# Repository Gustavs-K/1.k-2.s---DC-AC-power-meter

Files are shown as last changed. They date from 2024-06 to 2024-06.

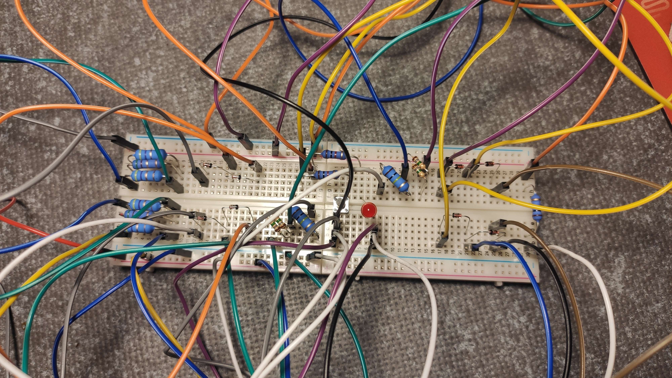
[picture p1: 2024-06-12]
Praktiskie_atteli/Elek_prototype_image2.jpg

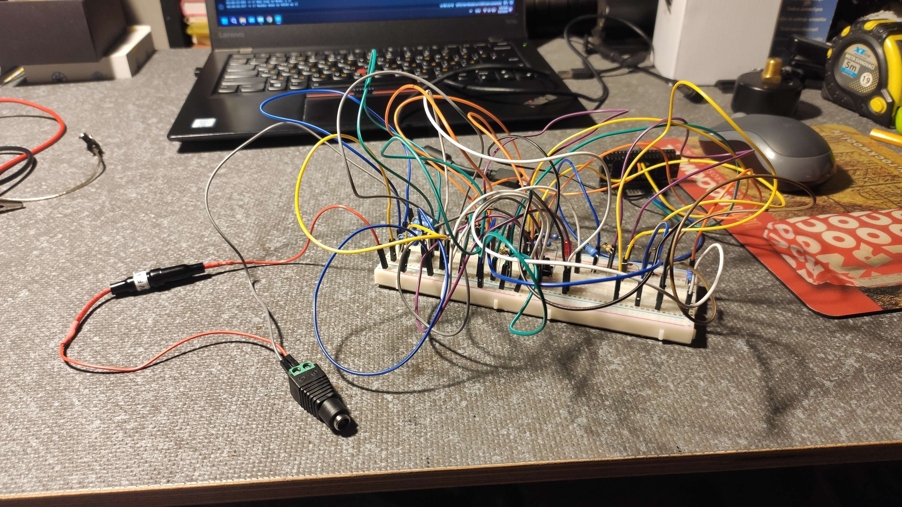
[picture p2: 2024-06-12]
Praktiskie_atteli/Elek_prototype_image1.jpg

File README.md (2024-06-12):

# 1.k 2.s DC/AC power meter

Elek_merijumu-jaudas_metrs / Elek_merijumu-jaudas_metrs.ino --- Kods

Praktiskie_atteli / ... --- Praktiskā prototipa attēli

DC AC power meter - atskaite.docx --- Atskaite

Elek-mer-projekts.fzz --- Fritzint makets

Parallel-resistor-calc.xlsx --- Paralelo rezistoru kalkulators

Power-meter-fritzing_mockup.png --- Fritzing maketa bilde

Power-meter_LTspice_model.png --- LTspice modeļa bilde

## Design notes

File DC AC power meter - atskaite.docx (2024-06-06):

DC / AC jaudas mērītājs // Atskaite

Kods, atskaite un vairāki pielikumi ir arī pieejami GitHub:
https://github.com/Gustavs-K/1.k-2.s-DC-AC-power-meter/

Kods satur komentārus, kas paskaidros koda darbību daudz dziļākā līmenī.
Visi komentāri ir angļu valodā.

# Īss aprakts

Projekta galvenais mērķis ir izveidot jaudas mērītāju, kas spēj nomērīt un aprēķināt līdzstrāvas un maiņstrāvas spriegumus, strāvas stiprumus un jaudas.

Projekts iekļauj ESP32, kas pilda ADC un informācijas apstrādes funkcijas un vairākas elektroniskās ierīces, kas pārveido ienākošo spriegumu un slodzes patērēto stāvas stiprumu uz MCU nolasāmu formu un veic citas funkcijas.

# Galvenās funkcijas

Mikrokontrolleris – ESP32_Devtikc_V4 – ADC , datu apstrāde, datu izvade caur “serial monitor”,

2x Sprieguma dalītājs – samazina nolasāmo spriegumu, lai iekļautos ESP32 3.3V nolasāmajā diapazonā,

2x Pilna viļņa taisngriezis – pārveido negatīvo maiņstrāvas spriegumu uz pozitīvu un ar ESP32 nolasāmu,

Šunta rezistors – Strāvas stipruma mērīšanai

LED (sarkans) – pārsprieguma indikators,

Poga – DC / AC režīma pārslēgšanai.

# Saturs

# Elektronika

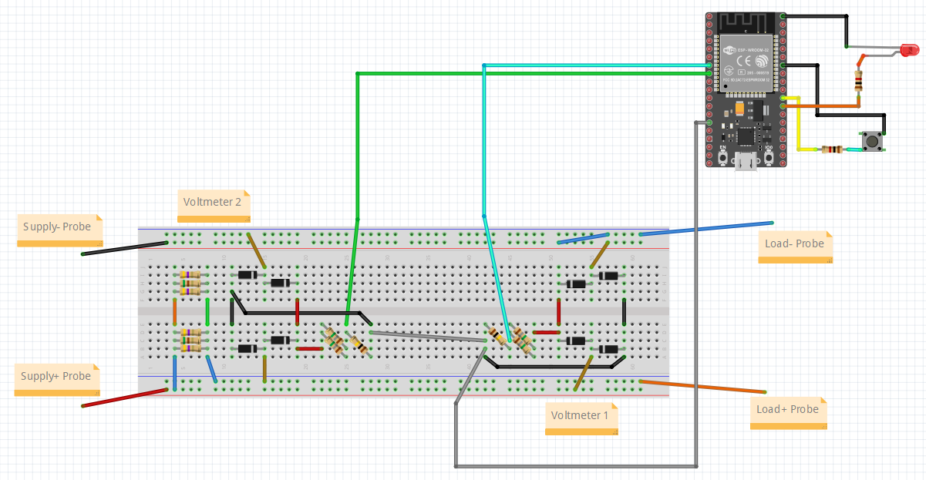
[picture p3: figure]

## Voltmetri

Voltmetri sastāv no pilna viļņa taisngrieža, sprieguma dalītāja un ESP32 analogās ieejas. V1 mēra kopējo ķēdes spriegumu un V2 mēra spriegumu pēc šuntes, lai varētu aprēķināt tās sprieguma kritumu.

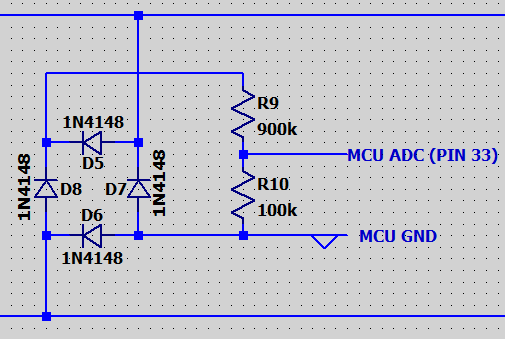
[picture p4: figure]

Oriģināli bija iedomāta sistēma ar vairākiem režīmiem, kurā katrs režīms pielietotu savu detaļu kombināciju. Šī ideja tika atmesta, lai vienkāršotu jaudas metra pielietošanu un izveidi, bet tādējādi arī zaudējot mazliet precizitāti un ieviešot apgrūtinājumus datu apstrādē.

## Sprieguma dalītājs

Spieguma dalītājs sastāv no diviem 1.8M Ω rezistoriem (kopā 900k Ω) un viena 100k Ω rezistora. Šīs vērtības kopā izveido izejas pret ieejas sprieguma attiecību 1/10, kas palielina ESP32 nolasāmo diapazonu no 3.3V uz 33V.

Lielās rezistoru vērtības tika izvēlētais, lai samazinātu voltmetru ietekmi uz mērāmās ķēdes darbību.

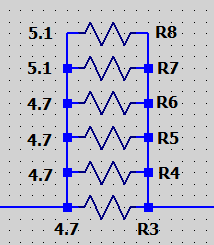
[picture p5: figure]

## Šuntes rezistors

Šuntes rezistors sastāv no sešiem, paralēli novietotiem, rezistoriem, kuru vērtības ir 4x 4.7 Ω un 2x 5.1 Ω. Oriģināli 0.805 Ω šunte bija iedomāta, bet, pieejamo rezistoru vērtību dēļ, 0.8044 Ω bija tuvākā iegūstamā kopējā pretestība, kas spētu izdalīt pietiekami daudz jaudas un izmantotu pēc iespējas mazāku rezistoru daudzumu. 0.805 Ω tika izvēlēts, lai pie maksimālā nomērāmā spieguma krituma (3.3V) strāvas stiprums būtu apmēram 4 ampēri.
Meklējot rezistoru kombināciju, maksimālais plānotais strāvas stiprums tika samazināts līdz 3 ampēriem.

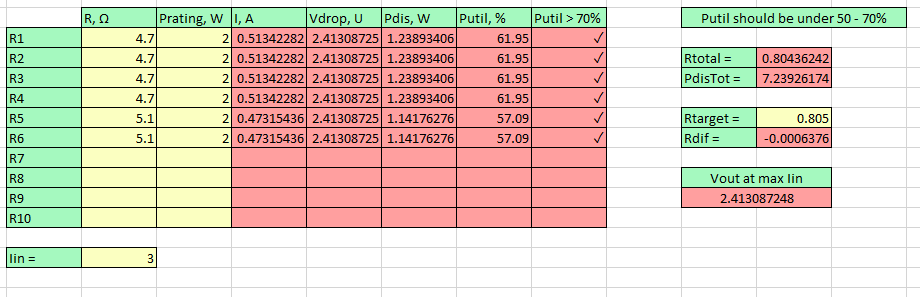
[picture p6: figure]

Izveidojot voltmetra maketu, maksimālais strāvas stiprums samazinājās līdz 1 ampēram, maketēšanas plates un vadu savienojumu dēļ.

## Pilna viļņa taisngriezis

Pilna viļņa taisngriezis ir izveidots no 1N4148 diodēm. Šī detaļa tiek izmantota, lai pārveidota maiņstrāvas negatīvās vērtības uz pozitīvām, kuras ESP32 var nolasīt.

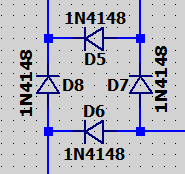
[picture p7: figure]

Mērot līdzstrāvu šis taisngriezis darbojas kā pret polaritātes aizsardzība.

Šis taisngriezis nesatur filtra kondensatoru, jo tas apgrūtinātu datu apstrādi un mērījumu veikšanai tas nav nepieciešams.

Viens no taisngrieža lielākajiem mīnusiem ir diožu sprieguma kritums, kas iespaido gan līdzstrāvas, gan maiņstrāvas mērījumu precizitāti.

## Poga un LED

Pogas galvenā funkcija ir DC / AC režīma pārslēgšana. Šis režīms maina apstrādes laikā veiktās funkcijas un izvadītos datu.

LED indikators norāda uz pārspriedumu uz ESP32 analogajām ieejām. Šī funkcija tiek veikta ar koda palīdzību. Ekstrēmos gadījumos indikators varētu nestrādāt kā iecerēts.

## ESP32

ESP32 ADC ir ļoti ierobežots. Kaut arī tas ir 12 bitu ADC, tā mērījumi var būt ievērojami atšķirties, sevišķi pie maksimālajām un minimālajām vērtībām, kur mērījumi sāk ievērojami diverģēt no īstā sprieguma.

ESP32 datu apstrādes spējas ir ļoti labas, divu kodolu un 80 – 240 MHz takts frekvences dēļ. Vidējais koda cikla laiks ir ≈80 ms, no kura ≈60 ms ir analogo datu nolasīšana un ≈10µs datu apstrāde.

## Cenas aprēķins:

ESP32-DEVKITC-S1 – 17.13 EUR

1N4148 diode – 0.04 EUR x8

Rezistori :

4.7 Ω, 2W – 0.09 EUR x4

5.1 Ω, 2W – 0.20 EUR x2

1k Ω – 0.09 EUR x2

100k Ω – 0.09 EUR x2

1.8M Ω – 0.01 EUR x4

LED (sarkans) – 0.06 EUR

Maketēšanas plate – 4.83 EUR x2

Kopējā cena – ≈28.33 EUR

# Koda apraksts

Galvenais cikls sastāv ko 4 galvenajām funkcijām, starp kurām tiek nomērīti šo funkciju darbības laiki.

## varResetter() funkcija

Šī funkcija pārmaina visu aprēķināto mainīgo vērtības uz 0, lai nodrošinātu, ka iepriekšējie cikli neietekmē šī cikla aprēķinus.

## inputReader() funkcija

inputReader() galvenokārt nolasa un saglabā V1 un V2 analogās vērtības, pārbauda un veic pogas funkcijas un pārbauda un ieslēdz pārsprieguma LED.

## dataProcessor() funkcija

Šī funkcijas apstrādā nolasītos datus, lai iegūt vērtības, kuras nav iespējams tieši nolasīt. Dati, kurus šī funkcija aprēķina, ir atkarīgi no režīma. DC režīmā tiek aprēķināts vidējais strāvas stiprums un jauda. AC režīmā tiek aprēķinātas RMS vērtības priekš V1, V2, I, īstā jauda, šķietamā jauda, reaktīvā jauda un jaudas faktors.

## outputPrinter() funkcija

outputPrinter() izvada visas izvadāmo mainīgo vērtības serial monitora. Līdzīgi dataProcessor(), šī funkcijas izvadītā informācija ir atkarīga no darbības režīma.

RTU // EVIF // RECO 0 // Gustavs Krūzmanis // 231REC066

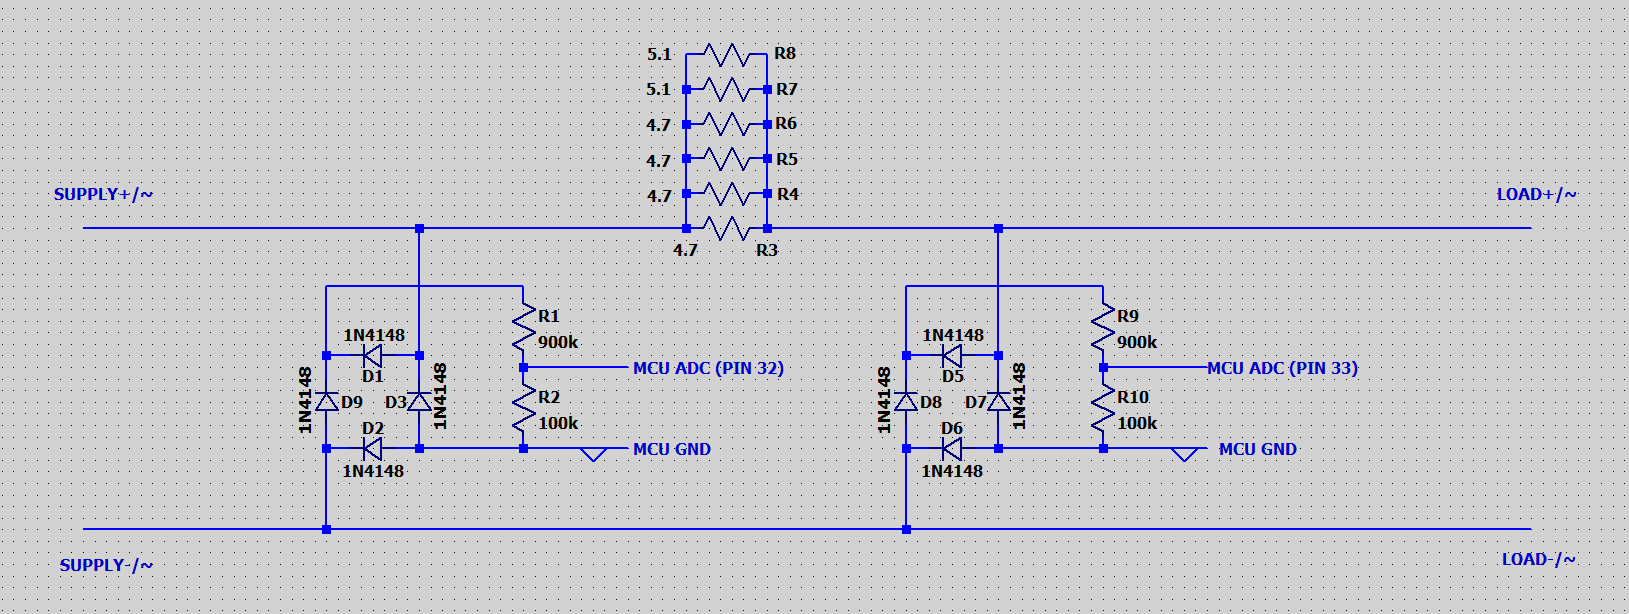
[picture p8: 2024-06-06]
Power-meter_LTspice_model.png

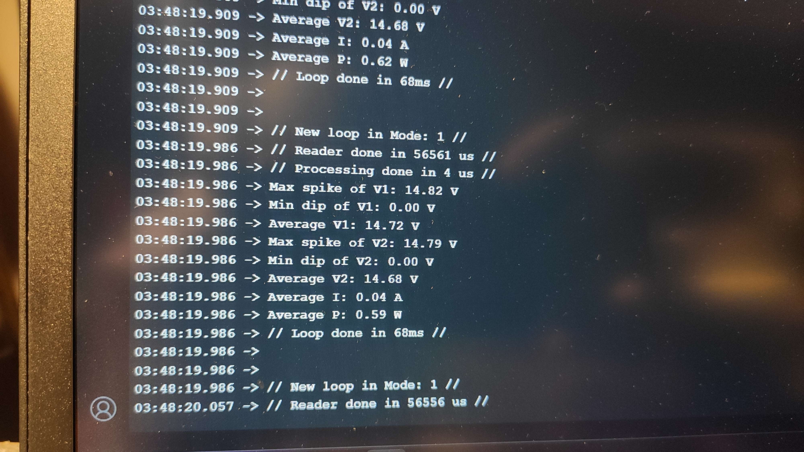
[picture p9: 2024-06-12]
Praktiskie_atteli/Elek_prototype_image-merijumi1.jpg

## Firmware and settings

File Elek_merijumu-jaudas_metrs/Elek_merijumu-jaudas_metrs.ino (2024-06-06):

#include <Arduino.h>

// Main info
// 2 Modes: 1) DC Power ; 2) AC Power

// Mode info:
// 1) DC P --- Terminals(4): Supply in/out , Load in/out ; ONLY IN SERIES ; SPLY- & LOAD- connected , Voltage(SPLY+/SPLY- --> VD1 --> MCU) , Amperage(SPLY+/LOAD+ --> SHNT --> VD2 --> MCU)
// 2) AC P --- Terminals(4): Supply in/out , Load in/out ; ONLY IN SERIES ; SPLY- & LOAD- connected , Voltage(SPLY+/SPLY- --> FWB1 --> VD1 --> MCU) , Amperage(SHNT --> FWB2 --> VD2 -->  MCU)

// Devices:
// ESP32 (MCU)               ---  PINS: 
// Indicator LED red (LEDR)  ---  For over voltage warning
// Voltage devider (VD1)     ---  For V1
// Voltage devider (VD2)     ---  For V2 (I)
// Shunt resistor (SHNT)     ---  For I
// Full wave bridge 1 (FWB1) ---  For AC V1
// Full wave bridge 2 (FWB2) ---  For AC V2 (I)

// Measured power supply (SPLY)
// Measured load (LOAD)

// Button debuging, leave undefined for no extra info
#define BUTTON_DEBUGING_SERIAL_INFO 

// Leave undifined for no extra timers
#define MORE_TIME_MEASUREMENTS 1

// Analog input buffer size
#define BUFFER_SIZE 200

// Shunt resistors resistance
#define SHUNT_RESISTANCE 0.80436242

// Defins the output to input ratio of voltage dividors (1 / x)
#define VD1_RATIO 10
#define VD2_RATIO 10

// Defines least significant bits
#define LSB_V1 3.3F/4095.0f
#define LSB_V2 3.3F/4095.0f
#define LSB_I LSB_V2
#define LSB_P LSB_V1*LSB_I

// Pins
#define PIN_V1 33
#define PIN_V2 32
#define PIN_LED 16
#define PIN_BUTTON 17

// Stores if button is pressed down
int buttonState;
// Denots the current selected mode
uint16_t selectedMode = 1;

// Buffers for analog measurements (voltage and amperage)
uint16_t bufferV1[BUFFER_SIZE];
uint16_t bufferV2[BUFFER_SIZE];

// Processing variables
uint64_t sumV1 = 0;
uint64_t sumV2 = 0;

// Unique to AC
int64_t rmsSumV1 = 0;
int64_t rmsSumV2 = 0;
int64_t rmsSumI = 0;
int64_t realPowerSum = 0;

// Output variables
float spikeMaxV1 = 0;
float spikeMaxV2 = 0;

float dipMinV1 = 4095;
float dipMinV2 = 4095;

float avgV1 = 0;
float avgV2 = 0;

float avgI = 0;

// Unique to DC
float avgP = 0;

// Unique to AC
float rmsV1 = 0;
float rmsV2 = 0;
float rmsI = 0;
float realPower = 0;
float apparentPower = 0;
float reactivePower = 0;
float powerFactor = 0;

// Only executed on power on
void setup() {
  // Starts serial monitor, with baud rate of 115200
  Serial.begin(115200);
  Serial.println("// Start up begin //");

  // Initiates the pins
  pinMode(PIN_V1, INPUT);
  pinMode(PIN_V2, INPUT);
  pinMode(PIN_LED, OUTPUT);
  pinMode(PIN_BUTTON, INPUT_PULLUP);

  // Turns the LED off
  digitalWrite(PIN_LED, LOW);
  
  // Measures the length of the setup function in milliseconds
  unsigned long millisOut = millis();
  Serial.print("// Start up done in ");
  Serial.print(millisOut);
  Serial.println("ms //");
}

void loop() {
  
  Serial.print("\n// New loop in Mode: ");
  Serial.print(selectedMode);
  Serial.println(" //");
  unsigned long loopMillis = millis();

  // Only adds extra timer variables, if extra timers ar on
  #ifdef MORE_TIME_MEASUREMENTS
    unsigned long readerMicros;
    unsigned long processingMicros;
  #endif
  
  // Resets variables, so last cycle dosn't effect this cycle
  varResetter();  

  // Extra timer for reader starts
  #ifdef MORE_TIME_MEASUREMENTS
    readerMicros = micros();
  #endif

  // Reads and writes analog inputs, handels button and LED functions 
  inputReader();

  // Extra timer for inputReader ends and dataProcessor starts
  #ifdef MORE_TIME_MEASUREMENTS
    readerMicros = micros() - readerMicros;
    Serial.print("// Reader done in ");
    Serial.print(readerMicros);
    Serial.println(" us //");

    processingMicros = micros();
  #endif

  // Processes analog data
  dataProcessor();

  // Extra timer for dataProcessor ends
  #ifdef MORE_TIME_MEASUREMENTS
    processingMicros = micros() - processingMicros;
    Serial.print("// Processing done in ");
    Serial.print(processingMicros);
    Serial.println(" us //");
  #endif

  // Prints outputs to serial monitor
  outputPrinter();

  Serial.print("// Loop done in ");
  loopMillis = millis() - loopMillis;
  Serial.print(loopMillis);
  Serial.println("ms //\n");
}

// Resets variables, so last cycle dosn't effect this cycle
void varResetter(){
  
  // Processing variables
  sumV1 = 0;
  sumV2 = 0;

  // Unique to AC
  rmsSumV1 = 0;
  rmsSumV2 = 0;
  rmsSumI = 0;
  realPowerSum = 0;

  // Output variables
  spikeMaxV1 = 0;
  spikeMaxV2 = 0;

  dipMinV1 = 4095;
  dipMinV2 = 4095;

  avgV1 = 0;
  avgV2 = 0;

  avgI = 0;

  // Unique to DC
  avgP = 0;

  // Unique to AC
  rmsV1 = 0;
  rmsV2 = 0;
  rmsI = 0;
  realPower = 0;
  apparentPower = 0;
  reactivePower = 0;
  powerFactor = 0;

}

// Reads and writes analog inputs, handels button and LED functions
void inputReader(){
  // 4 = button was pressed down / 2 = button was up
  int buttonLatch;
  bool ledStillOn;

  // Cycle every buffer entry
  for(int i = 0; i < BUFFER_SIZE; i++){
    // Reads button state 
    buttonState = digitalRead(PIN_BUTTON);
    ledStillOn = false;

    // Button checker
    // Only execute every 10th cycle
    if (i % 10 == 0){
      // Switch statement uses a hash, that is comprised of the current button state and the previous for cycles button state
      switch (buttonState + buttonLatch){
        default:
          buttonLatch = 2;
          Serial.println("/// BUTTON HASH MISMATCH ERROR ///");
        break;

        case 3:
          // Not pressed / wasn't pressed
          #ifdef BUTTON_DEBUGING_SERIAL_INFO
            // Serial.println("No button activity");
          #endif
        break;

        case 2:
          // Is pressed / wasn't pressed
          Serial.println("BUTTON CLICK!!!");

          buttonLatch = 4;

          ++selectedMode;
          if(selectedMode >= 3){
            selectedMode = 1;
          }

        break;

        case 5:
          // Isn't pressed / was pressed
          buttonLatch = 2;
          #ifdef BUTTON_DEBUGING_SERIAL_INFO
            // Serial.println("BUTTON RESET");
          #endif
        break;

        case 4:
          // Is pressed / was pressed
          #ifdef BUTTON_DEBUGING_SERIAL_INFO
            // Serial.println("Button is held down");
          #endif
        break;
      }

    }

    // Read and store an analog value for each buffer entry
    bufferV1[i] = analogRead(PIN_V1);
    bufferV2[i] = analogRead(PIN_V2);
    // Every buffer entry together
    sumV1 += bufferV1[i];
    sumV2 += bufferV2[i];
    
    // Check every buffer entry and store the highest and lowest ones
    if((float)bufferV1[i] > spikeMaxV1){
      spikeMaxV1 = (float)bufferV1[i];
    }
    else if ((float)bufferV1[i] < dipMinV1){
      dipMinV1 = (float)bufferV1[i];
    }

    if((float)bufferV2[i] > spikeMaxV2){
      spikeMaxV2 = (float)bufferV2[i];
    }
    else if ((float)bufferV2[i] < dipMinV2){
      dipMinV2 = (float)bufferV2[i];
    }

    // Over voltage warning checker
    if(bufferV1[i] > 3700){
      digitalWrite(PIN_LED, HIGH);
      ledStillOn = true;
      Serial.println("/// V1 IS OVER 3V ///");
    }
    if(bufferV2[i] > 3700){
      digitalWrite(PIN_LED, HIGH);
      ledStillOn = true;
      Serial.println("/// V2 IS OVER 3V ///");
    }
    if(ledStillOn == false){
      digitalWrite(PIN_LED, LOW);
    }

    delayMicroseconds(200);
  }

}

// Processes analog data
void dataProcessor(){
  // Calculate average by deviding the sum of all buffer entries by the buffer entry count
  avgV1 = sumV1/(float)BUFFER_SIZE;
  avgV2 = sumV2/(float)BUFFER_SIZE;

  // Depending on selected mode, calculate different things
  switch(selectedMode){
    case 1:
      // If DC mode
      // Calculate average current and power
      avgI = (avgV1 - avgV2) / SHUNT_RESISTANCE;
      avgP = avgV1 * avgI;
    break;

    case 2:
      // If AC mode
      // Cycle through all buffer entries
      for(int i = 0; i < BUFFER_SIZE; i++){
        // Sum all buffer entries after squaring them
        rmsSumV1 += (int64_t)(bufferV1[i]*bufferV1[i]);
        rmsSumV2 += (int64_t)(bufferV2[i]*bufferV2[i]);

        // Calculate the sum of all RMS currents and powers
        rmsSumI += (int64_t)( (bufferV1[i] - bufferV2[i]) / SHUNT_RESISTANCE );
        realPowerSum += (int64_t)(bufferV1[i] * ((bufferV1[i] - bufferV2[i]) / SHUNT_RESISTANCE ) );
      } 

      // Calculate the AC specific variables
      rmsV1 = sqrt(rmsSumV1/(float)BUFFER_SIZE);
      rmsV2 = sqrt(rmsSumV2/(float)BUFFER_SIZE);
      rmsI = sqrt(rmsSumI/(float)BUFFER_SIZE);
      realPower = realPowerSum/(float)BUFFER_SIZE;
      apparentPower = rmsV1*rmsI;
      reactivePower = sqrt(apparentPower*apparentPower-realPower*realPower);
      powerFactor = realPower/apparentPower;
    break;

    default:
      // If mode is out of range (1 or 2), return error
      Serial.println("/// SELECTED MODE ERROR ///");
    break;
  }
}

// Prints outputs to serial monitor
void outputPrinter(){
  // General info for voltage 1
  Serial.print("Max spike of V1: ");
  Serial.print(spikeMaxV1 * LSB_V1 * VD1_RATIO);
  Serial.println(" V");

  Serial.print("Min dip of V1: ");
  Serial.print(dipMinV1 * LSB_V1 * VD1_RATIO);
  Serial.println(" V");

  Serial.print("Average V1: ");
  Serial.print(avgV1 * LSB_V1 * VD1_RATIO);
  Serial.println(" V");

  // General info for voltage 2
  Serial.print("Max spike of V2: ");
  Serial.print(spikeMaxV2 * LSB_V2 * VD2_RATIO);
  Serial.println(" V");

  Serial.print("Min dip of V2: ");
  Serial.print(dipMinV2 * LSB_V2 * VD2_RATIO);
  Serial.println(" V");

  Serial.print("Average V2: ");
  Serial.print(avgV2 * LSB_V2 * VD2_RATIO);
  Serial.println(" V");

  switch(selectedMode){
    case 1:
      // DC info
      Serial.print("Average I: ");
      Serial.print(avgI * LSB_I * VD2_RATIO);
      Serial.println(" A");

      Serial.print("Average P: ");
      Serial.print(avgP * LSB_P * VD1_RATIO * VD2_RATIO);
      Serial.println(" W");
    break;

    case 2:
      // AC info
      Serial.print("RMS of V1: ");
      Serial.print(rmsV1 * LSB_V1 * VD1_RATIO);
      Serial.println(" V");

      Serial.print("RMS of V2: ");
      Serial.print(rmsV2 * LSB_V2 * VD2_RATIO);
      Serial.println(" V");

      Serial.print("RMS of I: ");
      Serial.print(rmsI * LSB_I * VD2_RATIO);
      Serial.println(" A");

      Serial.print("Real power: ");
      Serial.print(realPower * LSB_P * VD1_RATIO * VD2_RATIO);
      Serial.println(" W");

      Serial.print("Apparrent power: ");
      Serial.print(apparentPower * LSB_P * VD1_RATIO * VD2_RATIO);
      Serial.println(" VA");

      Serial.print("Reactive power: ");
      Serial.print(reactivePower * LSB_P * VD1_RATIO * VD2_RATIO);
      Serial.println(" VAR");

      Serial.print("Power factor: ");
      Serial.println(powerFactor);
    break;

    default:
      Serial.println("/// SELECTED MODE ERROR ///");
    break;
  }
}
